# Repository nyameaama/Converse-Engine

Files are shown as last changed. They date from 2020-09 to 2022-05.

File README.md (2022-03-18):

# Converse-Engine

Pressure-Fed Cycle Based Liquid Rocket Engine integrated as a thruster.

**Propellants:**

Fuel : C3H8(L) 100%

Oxidizer: N20(L)

**Properties:**

Specific impulse (vac) : 268.45 s

Chamber Pressure : 700 psi

<p align = "center">
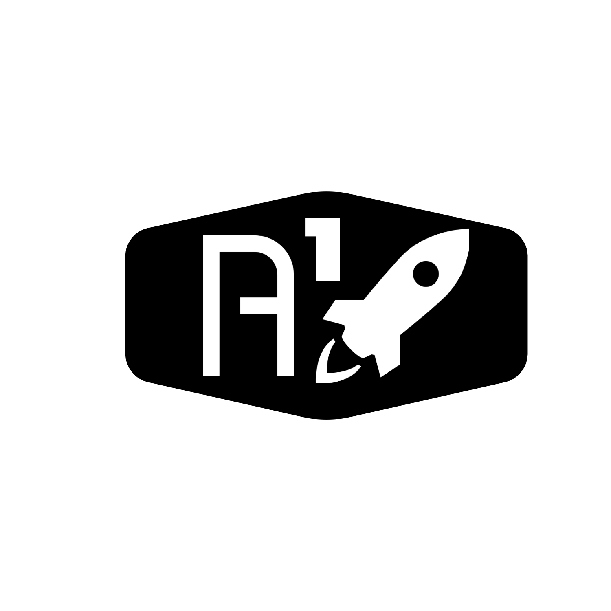
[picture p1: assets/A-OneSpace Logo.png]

</p>
<p align = "center">
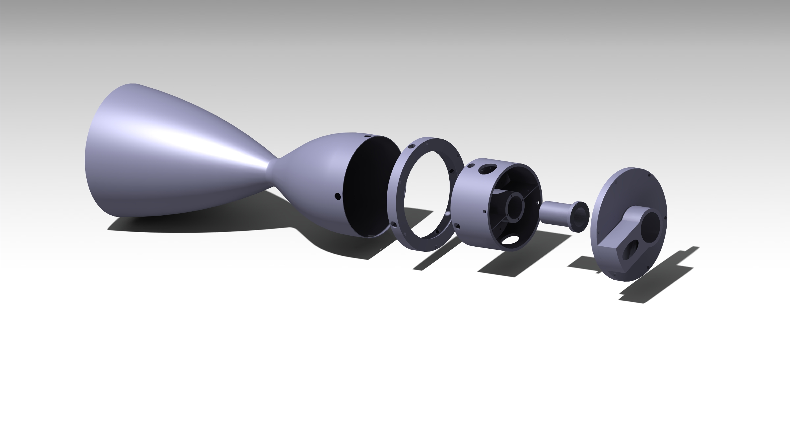
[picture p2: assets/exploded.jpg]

</p>
<p align = "center">
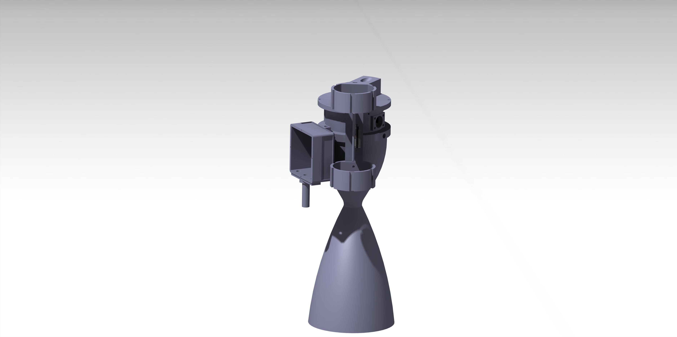
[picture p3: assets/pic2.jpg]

</p>
<p align = "center">
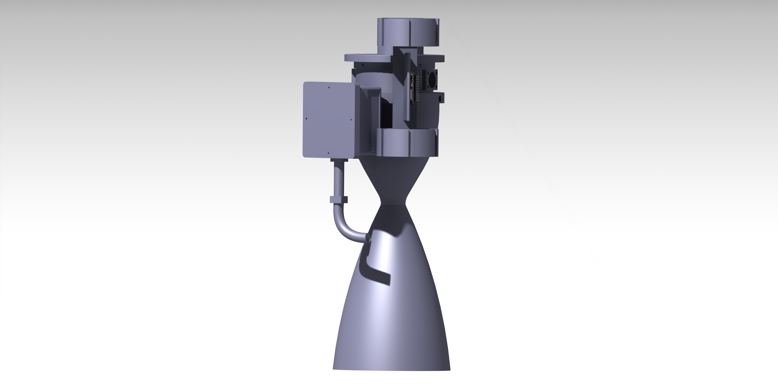
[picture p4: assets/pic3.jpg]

</p>

[A-OneSpace](https://github.com/A-OneSpace)

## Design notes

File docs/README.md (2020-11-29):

## Engine Docs

<p align = "center">
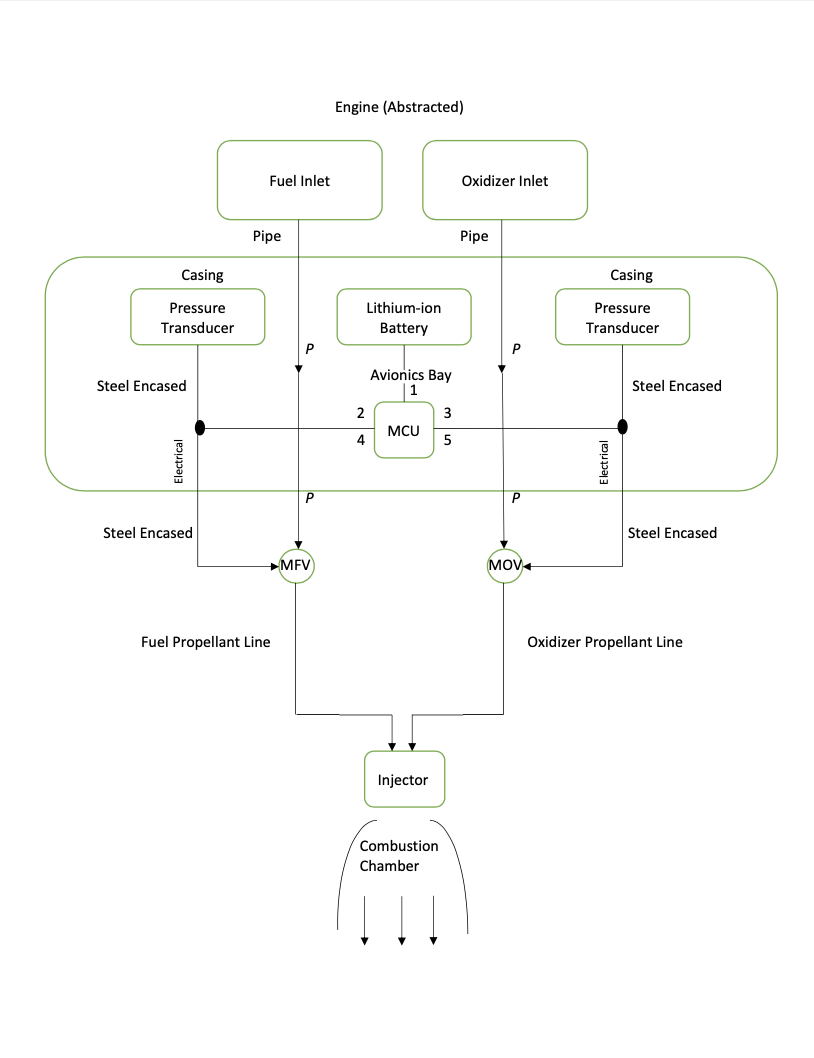
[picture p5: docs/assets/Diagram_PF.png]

</p>

See [Engine Abstracted](https://github.com/nyameaama/Converse-Engine/blob/master/docs/Engine%20Abstracted.pdf)

Pumps Battery and spark igniter documented separately. [See document]()

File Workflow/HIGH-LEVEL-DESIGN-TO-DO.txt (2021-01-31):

HIGH-LEVEL-DESIGN

Previous

- Begin detailing of purge system
- Jumper Wire detailing
- Electrical Piping analysis
- create scaled circuit
- Pipe Coupling detailing
- Begin pressure loss calculations

Current

- Updated Pressure Fed Cycle Design
- complete Engine equations
- nozzle expansion ratio lookover
- Nitrogen Gas Tank Design(Purge Sys)
- Helium Gas Tanks
- Power Assemblies

- Propellant piping analysis (Material, sizing)
- Regen cooling analysis
- injector assembly 

- pump analysis (Electric Pump Variant)
- Purge Valves (route)
- 2 way pipe (Purge Piping)

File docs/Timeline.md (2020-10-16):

# Design Stages and Timeline

Stage X - Avionics

- Sensor Component Analysis (Bill of Materials + Datasheets)
- Design Custom PCB (STM32H7 mcu)
- Avionics Unit Design
- Engine Control Unit Software
- Component Casings CAD

Stage XX - General Design 

- Requirements Analysis (Propellants)
- Nozzle Design
- Combustion Chamber Design
- Pintle injector
- Design CAD

Stage XXX - Piping and Plumbing

- Components Analysis (Pumps, Solenoid Valves)
- Pipe routing (Avionics, Propellant)

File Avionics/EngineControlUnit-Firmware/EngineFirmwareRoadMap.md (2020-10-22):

# Firmware RoadMap

STM32F7 

## Component Drivers Development

Control:
- Solenoid Valve
- Pump 

Measurement:
- Pressure Transducers
- Thermocouple

## Battery Management 

- Lithium Ion Battery Interface

## Engine Control

- Starting enigine
- Terminating engine

## AETS (Automatic Engine Termination System)

- AETS compares simulation data to actual engine performance. If operation is not in bounds engine is terminated

## Telemetry-Communication Module

-  Compile transducer and thermocouple data and send comms

## Engine Setup

- State
* ARMED -> 1 minute timer |  
* PREP -> 
* IDLE -> NO PROCESS | init terminal connection

** IF CONNECTION TO TERMINAL-CONTROLLER BREAKS, ENGINE OPERATION STOPS

Pre-conditioning Systems

- Engine Chill
* Check pipe temps
* if temps < (t(nominal)) -> Start chill
* Open LOX valves
* Pipe temp Feedback Control

- Engine Purging
* Remove residual propellant through gas flow

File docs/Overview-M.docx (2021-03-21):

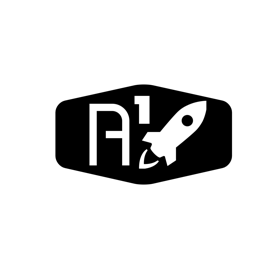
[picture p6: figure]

DESIGN DOCUMENT

Area : Converse Engine

Category: Feed (Struct)

TEAM: Propulsion

Nyameaama Gambrah

Injector Assembly

Engine Mount

Merge Plates

Merge Plates

Chamber

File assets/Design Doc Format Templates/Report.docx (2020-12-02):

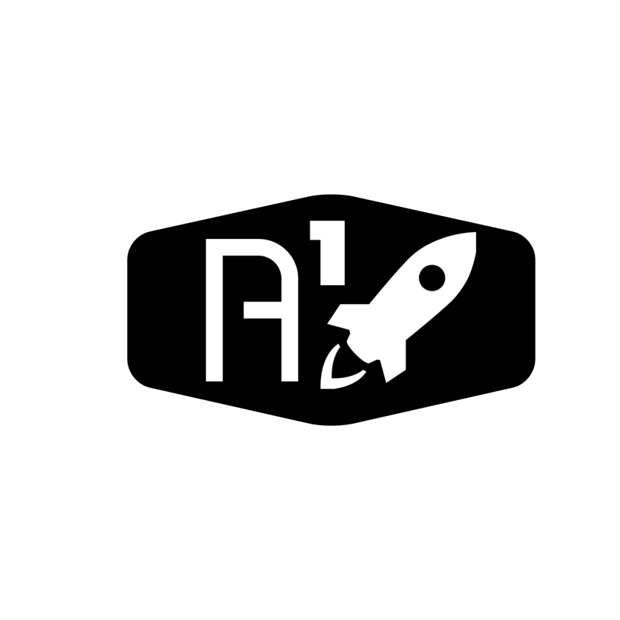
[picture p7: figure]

Lead: ……………………………

Nov 26, 2020

Nyameaama Gambrah

A-OneSpace : Converse Engine Chamber Nozzle Design

ABSTRACT

Lorem ipsum dolor sit amet, consectetur adipiscing elit, sed do eiusmod tempor incididunt ut labore et dolore magna aliqua. Tincidunt eget nullam non nisi. Amet risus nullam eget felis eget nunc lobortis mattis aliquam. Suspendisse in est ante in. Sit amet facilisis magna etiam. Nunc mattis enim ut tellus elementum sagittis vitae et. Ut porttitor leo a diam sollicitudin. Id volutpat lacus laoreet non curabitur gravida arcu. Dignissim sodales ut eu sem integer vitae justo eget. A condimentum vitae sapien pellentesque habitant. Eu lobortis elementum nibh tellus molestie nunc non. Sit amet consectetur adipiscing elit duis tristique sollicitudin nibh sit.

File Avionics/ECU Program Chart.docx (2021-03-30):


DESIGN DOCUMENT

Area : Converse Engine

Category: Feed (Avionics)

TEAM: Propulsion

Nyameaama Gambrah

CONVERSE ENGINE CONTROL UNIT PROGRAM MODULES (ABSTRACTED)

Entry

Communication Module

Utility Module

Driver Router Module

RF Comms Driver

Program Temporary Access Memory

Measurement/ Analysis Module

d

GPIO

Engine Config

Pressure-T Drivers

Valve Drivers

Parser

FLASH STORE

Telemetry Packaging

Temp Drivers

Timers

Spark Plug Drivers

SBC-Comms

Engine Properties Calculations

Control Module

Testing

Set engine config

STATE MACHINE

Abort Manager

Telemetry

Active Operation

Preconditioning

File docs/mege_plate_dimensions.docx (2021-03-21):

DESIGN DOCUMENT

Area : Converse Engine

Category: Feed (Struct)

TEAM: Propulsion

Nyameaama Gambrah

MERGE PLATE

M-Bolt

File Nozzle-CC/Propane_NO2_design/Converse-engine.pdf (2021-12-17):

## Engine name: Converse

Mon Nov 29 20:46:48 2021

Propellant Specification
Component Temperature (K) Mass fraction Mole fraction
C3H8(L) | 231.08 | 0.19 | 0.18
N2O(L),298.15K | 298.15 | 0.81 | 0.82
| Total | 1.00 | 1.00
Exploded propellant formula:N1.630 O0.815 C0.555 H1.479
| O/F = 4.400
O/F⁰ = 9.981 (stoichiometric) αox = 0.441 (oxidizer excess coefficient)

Table 1. Thermodynamic properties

Parameter | Injector | Nozzle inlet | Nozzle throat | Nozzle exit | Unit
Pressure | 3.4474 | 3.4474 | 1.8973 | 0.0117 | MPa
Temperature | 2400.6726 | 2400.6726 | 2116.4505 | 823.2841 | K
Enthalpy | 666.6951 | 666.6951 | 129.7272 | -2476.5175 | kJ/kg
Entropy | 10.9970 | 10.9970 | 10.9970 | 10.9970 | kJ/(kg·K)
Internal energy | -290.2740 | -290.2740 | -713.5100 | -2790.7130 | kJ/kg
Specific heat (p=const) | 1.9405 | 1.9405 | 1.8640 | 10.3246 | kJ/(kg·K)
Specific heat (V=const) | 1.5351 | 1.5351 | 1.4634 | 8.7935 | kJ/(kg·K)
Gamma | 1.2641 | 1.2641 | 1.2738 | 1.1741
Isentropic exponent | 1.2636 | 1.2636 | 1.2736 | 1.1169
Gas constant | 0.3986 | 0.3986 | 0.3984 | 0.3816 | kJ/(kg·K)
Molecular weight (M) | 20.8579 | 20.8579 | 20.8686 | 21.7864
Molecular weight (MW) | 0.02086 | 0.02086 | 0.02087 | 0.02124
Density | 3.6024 | 3.6024 | 2.2500 | 0.0372 | kg/m³
Sonic velocity | 1099.6349 | 1099.6349 | 1036.3089 | 592.3949 | m/s
Velocity | 0.0000 | 0.0000 | 1036.3089 | 2507.2745 | m/s
Mach number | 0.0000 | 0.0000 | 1.0000 | 4.2324
Area ratio | infinity | infinity | 1.0000 | 25.0000
Mass flux | 0.0000 | 0.0000 | 2331.7360 | 93.2322 | kg/(m²·s)
Mass flux (relative) | 0.000e-04 | 0.000e-04 | | | kg/(N·s)
Viscosity | 7.56e-05 | 7.56e-05 | 6.929e-05 | 3.673e-05 | kg/(m·s)
Conductivity, frozen | 0.2451 | 0.2451 | 0.2198 | 0.1049 | W/(m·K)
Specific heat (p=const), frozen | 1.852 | 1.852 | 1.822 | 1.581 | kJ/(kg·K)
Prandtl number, frozen | 0.5711 | 0.5711 | 0.5744 | 0.5533
Conductivity, effective | 0.2826 | 0.2826 | 0.2332 | nan | W/(m·K)
Specific heat (p=const), effective | 1.941 | 1.941 | 1.864 | 1.581 | kJ/(kg·K)
Prandtl number, effective | 0.5191 | 0.5191 | 0.5539 | nan

Table 2. Fractions of the combustion products

Species | Injector Injector Nozzle inlet Nozzle inlet mass | mole
mass | mole fractions | fractions fractions
fractions

Nozzle Nozzle Nozzle exit Nozzle exit throat throat mass mole
mass | mole | fractions | fractions
| | | | | fractions | fractions
C(gr) | | | | | | | 0.0141885 0.0250908
CH4 | 0.0000002 | 0.0000002 | 0.0000002 | 0.0000002 | 0.0000002 | 0.0000003 | 0.0066388 0.0087896
CO | 0.3288592 | 0.2448866 | 0.3288592 | 0.2448866 | 0.3256783 | 0.2426427 | 0.1754557 0.1330459
CO2 | 0.0377299 | 0.0178817 | 0.0377299 | 0.0178817 | 0.0427448 | 0.0202689 | 0.2085925 0.1006702
1
Species | Injector mass fractions
Injector Nozzle inlet Nozzle inlet | Nozzle
| | | | | throat mass fractions | | Nozzle Nozzle exit Nozzle exit
| | mole fractions | mass fractions | mole fractions | | throat mole fractions
mass | mole
fractions | fractions
COOH | 0.0000003 | 0.0000001 | 0.0000003 | 0.0000001
H | 0.0000650 | 0.0013455 | 0.0000650 | 0.0013455 | 0.0000190 | 0.0003941
H2 | 0.0236045 | 0.2442308 | 0.0236045 | 0.2442308 | 0.0238767 | 0.2471740 | 0.0266082 0.2803491
H2O | 0.0910036 | 0.1053628 | 0.0910036 | 0.1053628 | 0.0890350 | 0.1031366 | 0.0498966 0.0588273
HCHO,formaldehy | 0.0000012 | 0.0000008 | 0.0000012 | 0.0000008 | 0.0000007 | 0.0000005
HCN | 0.0000148 | 0.0000114 | 0.0000148 | 0.0000114 | 0.0000085 | 0.0000066
HCO | 0.0000026 | 0.0000019 | 0.0000026 | 0.0000019 | 0.0000007 | 0.0000005
HCOOH | 0.0000007 | 0.0000003 | 0.0000007 | 0.0000003 | 0.0000004 | 0.0000002
HNC | 0.0000014 | 0.0000011 | 0.0000014 | 0.0000011 | 0.0000005 | 0.0000004
HNCO | 0.0000029 | 0.0000014 | 0.0000029 | 0.0000014 | 0.0000016 | 0.0000008
N2 | 0.5185805 | 0.3861180 | 0.5185805 | 0.3861180 | 0.5185934 | 0.3863262 | 0.5185982 0.3932003
NH2 | 0.0000005 | 0.0000007 | 0.0000005 | 0.0000007 | 0.0000001 | 0.0000001
NH3 | 0.0000246 | 0.0000302 | 0.0000246 | 0.0000302 | 0.0000199 | 0.0000244 | 0.0000213 0.0000266
NO | 0.0000111 | 0.0000077 | 0.0000111 | 0.0000077 | 0.0000014 | 0.0000010
O | 0.0000003 | 0.0000004 | 0.0000003 | 0.0000004
OH | 0.0000963 | 0.0001181 | 0.0000963 | 0.0001181 | 0.0000184 | 0.0000226

Table 3. Theoretical (ideal) performance
Parameter | Sea level | Sea level (flow sep.) | Optimum expansion | Vacuum | Unit
Characteristic velocity | | | 1478.46 | | m/s
Effective exhaust velocity | 1545.78 | 1768.87 | 2507.27 | 2632.59 | m/s
Specific impulse (by mass) | 1545.78 | 1768.87 | 2507.27 | 2632.59 | N·s/kg
Specific impulse (by weight) | 157.63 | 180.37 | 255.67 | 268.45 | s
Thrust coefficient | 1.0455

Table 4. Estimated delivered performance

1.1964 | 1.6959 | 1.7806
Parameter | Sea level | Sea level (flow sep.) | Optimum expansion | Vacuum | Unit
Characteristic velocity | | | 1438.85 | | m/s
Effective exhaust velocity | 1417.46 | 1643.14 | 2378.95 | 2504.26 | m/s
Specific impulse (by mass) | 1417.46 | 1643.14 | 2378.95 | 2504.26 | N·s/kg

Specific impulse (by weight) | 144.54 | 167.55 | 242.59 | 255.36

s
Thrust coefficient | 0.9851 | 1.1420 | 1.6534 | 1.7405
Ambient condition for optimum expansion: H=15.23 km, p=0.115 atm
2

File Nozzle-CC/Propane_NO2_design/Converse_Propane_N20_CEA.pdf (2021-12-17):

NASA-GLENN CHEMICAL EQUILIBRIUM PROGRAM CEA2, FEBRUARY 5, 2004 BY BONNIE MCBRIDE AND SANFORD GORDON REFS: NASA RP-1311, PART I, 1994 AND NASA RP-1311, PART II, 1996

*******************************************************************************

### CEA analysis performed on Tue 14-Dec-2021 15:02:54

# Problem Type: "Rocket" (Infinite Area Combustor)

prob case=Converse_______2705 ro equilibrium

# Pressure (1 value):

p,psia= 750
# Chamber/Exit Pressure Ratio (1 value): pi/p= 51.02

# Oxidizer/Fuel Wt. ratio (1 value):

o/f= 4.4

# You selected the following fuels and oxidizers: reac

fuel C3H8(L) | wt%=100.0000
oxid N2O | wt%=100.0000

# You selected these options for output:

# short version of output

output short
# Proportions of any products will be expressed as Mass Fractions. output massf

# Heat will be expressed as siunits

output siunits

# Input prepared by this script:/var/www/sites/cearun.grc.nasa.gov/cgi-bin/CEARU N/prepareInputFile.cgi

### IMPORTANT: The following line is the end of your CEA input file!

end

THEORETICAL ROCKET PERFORMANCE ASSUMING EQUILIBRIUM

COMPOSITION DURING EXPANSION FROM INFINITE AREA COMBUSTOR

Pin = 750.0 PSIA
CASE = Converse_______
REACTANT | WT FRACTION | ENERGY | TEMP
(SEE NOTE) | KJ/KG-MOL | K
FUEL | C3H8(L) | 1.0000000 | -128228.000 | 231.076
OXIDANT | N2O | 1.0000000 | 0.000 | 0.000
O/F= | 4.40000 | %FUEL= 18.518519 | R,EQ.RATIO= 2.268459 | PHI,EQ.RATIO= 2.268459
CHAMBER | THROAT | EXIT
Pinf/P | 1.0000 | 1.8248 | 51.020
P, BAR | 51.710 | 28.338 | 1.0135
T, K | 1751.69 | 1532.82 | 906.28
RHO, KG/CU M | 7.4122 0 4.6426 0 2.9816-1
H, KJ/KG | -538.51 | -931.32 -2414.33
U, KJ/KG | -1236.15 -1541.71 -2754.26
G, KJ/KG | -18495.7 -16644.7 -11704.9
S, KJ/(KG)(K) | 10.2513 | 10.2513 | 10.2513
M, (1/n) | 20.877 | 20.880 | 22.167
MW, MOL WT | 20.877 | 20.880 | 21.655
(dLV/dLP)t | -1.00030 -1.00056 -1.05903
(dLV/dLT)p | 1.0018 | 1.0045 | 2.0623
Cp, KJ/(KG)(K) | 1.8066 | 1.7967 | 9.2320
GAMMAs | 1.2836 | 1.2871 | 1.1284
SON VEL,M/SEC | 946.3 | 886.4 | 619.3
MACH NUMBER | 0.000 | 1.000 | 3.127

PERFORMANCE PARAMETERS

Ae/At | 1.0000 | 7.1255
CSTAR, M/SEC | 1256.6 | 1256.6
CF | 0.7054 | 1.5414
Ivac, M/SEC | 1575.0 | 2112.4
Isp, M/SEC | 886.4 | 1936.9

MASS FRACTIONS

CH4 | 0.00003 | 0.00008 | 0.01386
*CO | 0.31866 | 0.31151 | 0.17791
*CO2 | 0.05367 | 0.06478 | 0.18999
HCN | 0.00003 | 0.00002 | 0.00000
*H2 | 0.02437 | 0.02486 | 0.02326
H2O | 0.08463 | 0.08013 | 0.06355
NH3 | 0.00011 | 0.00011 | 0.00007
*N2 | 0.51851 | 0.51852 | 0.51855
C(gr) | 0.00000 | 0.00000 | 0.01280

* THERMODYNAMIC PROPERTIES FITTED TO 20000.K

NOTE. WEIGHT FRACTION OF FUEL IN TOTAL FUELS AND OF OXIDANT IN TOTAL OXIDANTS

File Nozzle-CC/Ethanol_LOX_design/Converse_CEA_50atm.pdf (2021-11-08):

NASA-GLENN CHEMICAL EQUILIBRIUM PROGRAM CEA2, FEBRUARY 5, 2004 BY BONNIE MCBRIDE AND SANFORD GORDON REFS: NASA RP-1311, PART I, 1994 AND NASA RP-1311, PART II, 1996

*******************************************************************************

### CEA analysis performed on Sat 06-Nov-2021 15:56:00

# Problem Type: "Rocket" (Infinite Area Combustor)

prob case=_______________1041 ro equilibrium

# Pressure (1 value):

p,atm= 50
# Chamber/Exit Pressure Ratio (1 value): pi/p= 50

# Oxidizer/Fuel Wt. ratio (1 value):

o/f= 1.3

# You selected the following fuels and oxidizers: reac

fuel C2H5OH | wt%=100.0000
oxid O2 | wt%=100.0000

# You selected these options for output:

# short version of output

output short
# Proportions of any products will be expressed as Mass Fractions. output massf

# Heat will be expressed as siunits

output siunits

# Input prepared by this script:/var/www/sites/cearun.grc.nasa.gov/cgi-bin/CEARU N/prepareInputFile.cgi

### IMPORTANT: The following line is the end of your CEA input file!

end

THEORETICAL ROCKET PERFORMANCE ASSUMING EQUILIBRIUM

COMPOSITION DURING EXPANSION FROM INFINITE AREA COMBUSTOR

Pin = 734.8 PSIA
CASE = _______________
REACTANT | WT FRACTION | ENERGY | TEMP
(SEE NOTE) | KJ/KG-MOL | K
FUEL | C2H5OH | 1.0000000 | 0.000 | 0.000
OXIDANT | O2 | 1.0000000 | 0.000 | 0.000
O/F= | 1.30000 | %FUEL= 43.478261 | R,EQ.RATIO= 1.475797 | PHI,EQ.RATIO= 1.602906
CHAMBER | THROAT | EXIT
Pinf/P | 1.0000 | 1.7358 | 50.000
P, BAR | 50.663 | 29.188 | 1.0132
T, K | 3635.79 | 3440.20 | 2297.51
RHO, KG/CU M | 3.3238 0 2.0512 0 1.1208-1
H, KJ/KG | 0.00000 | -812.23 -4695.86
U, KJ/KG | -1524.22 -2235.20 -5599.90
G, KJ/KG | -46826.0 -45119.2 -34286.0
S, KJ/(KG)(K) | 12.8792 | 12.8792 | 12.8792
M, (1/n) | 19.833 | 20.101 | 21.130
(dLV/dLP)t | -1.03555 -1.02889 -1.00147
(dLV/dLT)p | 1.6057 | 1.5209 | 1.0377
Cp, KJ/(KG)(K) | 6.7134 | 6.2566 | 2.6229
GAMMAs | 1.1435 | 1.1416 | 1.1906
SON VEL,M/SEC | 1320.2 | 1274.5 | 1037.5
MACH NUMBER | 0.000 | 1.000 | 2.954

PERFORMANCE PARAMETERS

Ae/At | 1.0000 | 7.6112
CSTAR, M/SEC | 1937.9 | 1937.9
CF | 0.6577 | 1.5814
Ivac, M/SEC | 2391.0 | 3359.6
Isp, M/SEC | 1274.5 | 3064.6

MASS FRACTIONS

*CO | 0.41573 | 0.40807 | 0.36716
*CO2 | 0.17741 | 0.18949 | 0.25382
COOH | 0.00003 | 0.00002 | 0.00000
*H | 0.00224 | 0.00188 | 0.00019
HCO | 0.00004 | 0.00002 | 0.00000
HO2 | 0.00008 | 0.00004 | 0.00000
*H2 | 0.01579 | 0.01550 | 0.01641
H2O | 0.32462 | 0.33529 | 0.36097
H2O2 | 0.00001 | 0.00001 | 0.00000
*O | 0.00658 | 0.00455 | 0.00002
*OH | 0.04591 | 0.03665 | 0.00139
*O2 | 0.01156 | 0.00849 | 0.00004

* THERMODYNAMIC PROPERTIES FITTED TO 20000.K

NOTE. WEIGHT FRACTION OF FUEL IN TOTAL FUELS AND OF OXIDANT IN TOTAL OXIDANTS

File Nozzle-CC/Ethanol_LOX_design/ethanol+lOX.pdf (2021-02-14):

## Liquid Oxygen & Ethyl Alcohol*

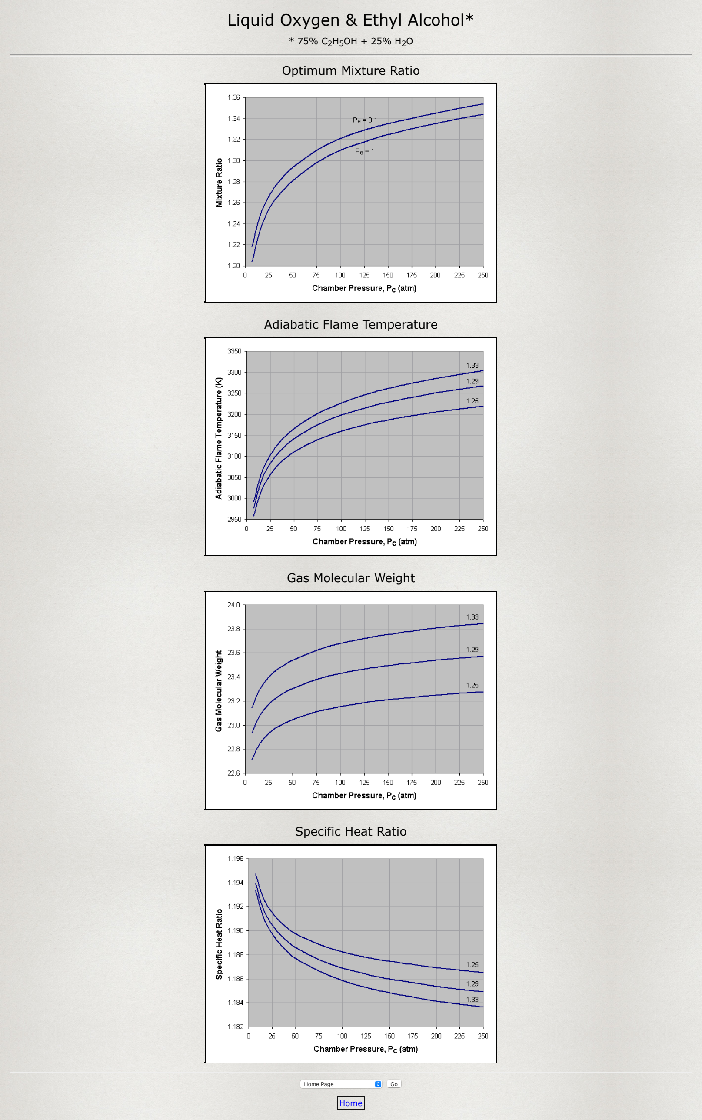
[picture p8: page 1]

* 75% C2H5OH + 25% H2O

Optimum Mixture Ratio

Adiabatic Flame Temperature

Gas Molecular Weight

Specific Heat Ratio

Home Page | Go

Home

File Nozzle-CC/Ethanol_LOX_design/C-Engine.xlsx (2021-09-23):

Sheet: VesselCharacteristics
 | Characteristics of a Vehicle in Motion |  |  |  |  |  |  |  |  |  |  |  |  |  |  |  |  |  |  |  |  |  | Chamber & Nozzle Measurements For Graph
 |  |  |  |  |  |  |  | 7.911e-05 | 5 | 0.005 |  |  |  |  |  |  |  |  |  | Propellent Mass Budget Analysis for Change in Velocity Increment |  |  | x | y-top | y-bottom | y-top-outer | y-bottom-outer | y-tube-top-upper | y-tube-top-lower | y-tube-bottom-upper | y-tube-bottom-lower
Instructions: This advanced equation takes a number of bipropellant liquid engine inputs and models a variety of outputs including: velocity, altitude, acceleration, nozzle dimensions, and heat-transfer. All input data should be filled in the yellow boxes. Anything in grey will be calculated automatically and green values are key outputs also calculated automatically. The charts will also update automatically. Note that thermal conductivity calculations do not consider carbon deposits or nucleate boiling |  |  |  |  |  |  |  |  |  |  |  |  |  |  |  |  |  |  |  | Velocity Increase (m/sec) | Propellent Mass (kg) | Change in Propellent Mass (kg) | 0 | 4.17130 | 0.303 | 4.47432 | 0.205 | 4.22051 | 4.37590 | 0.25381 | 0.0984251967
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

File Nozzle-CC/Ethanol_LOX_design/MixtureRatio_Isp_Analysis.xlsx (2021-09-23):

Mixture Ratio Analysis
Fuel-Rich | 100% Ethanol |  |  | Oxidizer-Rich | 100% Ethanol
Ratio (O/F) | Calculated Isp |  | Chamber Temp | Ratio (O/F) | Calculated Isp |  | Chamber Temp
 | (sec) | (m/sec) |  |  | (sec) | (m/sec) | (K)
1.1 | 264.8877551 | 2595.9 | 2780.28 | 1.1 | 264.8877551 | 2595.9 | 2780.28
1.2 | 271.3469388 | 2659.2 | 2983.22 | 2.1 | 278.7755102 | 2732 | 3453.72
1.3 | 276.4489796 | 2709.2 | 3145.17 | 3.1 | 258.7959184 | 2536.2 | 3311.35
1.4 | 280.2857143 | 2746.8 | 3265.37 | 4.1 | 241.2244898 | 2364 | 3117.26
1.5 | 282.9285714 | 2772.7 | 3347.88 | 5.1 | 225.8061224 | 2212.9 | 2911.2

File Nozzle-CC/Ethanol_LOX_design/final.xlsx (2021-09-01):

Final
Force Max (Fmax) = | 10000.00
Fuel/Oxidizer Specific Heat Ratio (k) | 1.185 | (Dimensionless)
Molecular Mass of Propellant Mixture (M) = | 24 | (Dimensionless)
Gas Constant (R) = | 8314 | j/Kg-K
Chamber Temperature (T1) = | 3030 | kelvin
Nozzle Inlet/Chamber Pressure (p1) = | 5.065578181 | pascal
Nozzle Exit Pressure (p2) = | 0.101325353 | pascal
Atomospheric Pressure (p3) = | 0.101325353 | pascal
Pressure Ratio (p2/p1) = | 0.02000272
Nozzle Throat Pressure (pt)= | 2.874247
Exhaust Velocity (v2) = | 12144.82 | m/sec
*Actual* Characteristic Velocity (c*) = | 7774.177582 | m/sec
Nozzle Area Ratio (At/A2) = | 0.1381
Thrust Coefficient (CF) = | 1.5622
Chamber Contraction Ratio (A1/At) = | 6.00
Chamber Cross Sectional Area = | 0.00758 | meters2
Chamber Diameter = | 0.09825 | meters
Chamber Length (L1)= | 0.1016 | meters
Nozzle Cone Convergence Half Angle (α) = | 60 | degrees
Convergence Length = | 0.01678419 | meters
Conical Frustum Length (Lc) = | 0.03356837 | meters
Chamber Volume (Vc)= | 0.001171195 | meters3
Chamber Characteristic Length (L*) = | 0.9268 | meters
Nozzle Throat Area = | 0.00126369 | meters2
Nozzle Throat Diameter = | 0.04011 | meters
Nozzle Throat Length = | 0.00079 | meters
Nozzle Exit Area = | 0.00915 | meters2
Nozzle Exit Diameter = | 0.10795 | meters
Nozzle Cone Diverence Half Angle (α) = | 15 | degrees
Nozzle Length = | 0.126584088 | meters
Nozzle Frustm Length (Nc) = | 0.131049491 | meters
Chamber Wall Thickness = | 0.0025 | meters

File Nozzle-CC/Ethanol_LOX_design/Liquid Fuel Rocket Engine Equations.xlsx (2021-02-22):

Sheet: Design
F | 23000 |  |  |  | Thrust, lbf
ωt | 63.55346781 |  |  |  | Propellant flow rate, lbs/s
Isp | 361.9 |  |  |  | Found in Flame Temps and Isp's
ωo | 45.39533415 |  |  |  | Oxidizer flow rate, lbs/s
ωf | 18.15813366 |  |  |  | Fuel flow rate, lbs/s
r | 2.5 |  |  |  | Mixture Ratio, found in tables
Tt | 5547.01797 |  |  |  | Throat Temperature
Tc | 6102.33 |  |  |  | Chamber Temperature
ºF | 5642.33 |  |  |  | Combustion Temperature, tables
Pt | 169.2 |  |  |  | Throat Pressure
Pc | 300 |  |  |  | Chamber Pressure, Tables
At | 36.2833017 |  | At01 | 0.3756115119 | Throat Area | At02 | 360556.168 | At03 | 38.64 | At04 | 9331.163769 | At05 | 96.5979491 | At06 | 36.2833017
R | 65 |  |  |  | Gas Constant
γ | 1.2 |  |  |  | Gamma
g | 32.2 |  |  |  | gravity
Dt | 6.79686211 | 3.398431055 |  |  | Throat Diameter, inches
π | 3.141592654 |  |  |  | pi
Ae | 132.4340512 |  |  |  | Exit area
De | 12.98538683 | 6.492693414 |  |  | Exit Diameter, inches
β | 60 | 30 | 0.5235987756 |  | Nozzle Angles
α | 15 | 75 | 1.308996939 | 0.2617993878
Lnozzle | 33.72892737 |  |  |  | Nozzle Length, in
Lconvergent | 12.68311736 |  |  |  | Convergent length, in
Ldivergent | 21.04581 |  |  |  | Divergent Length, in
L* | 60 |  |  |  | Don’t change
Vc | 2176.998102 |  |  |  | Chamber Volume, in^3
Dc | 33.98431055 |  |  |  | Chamber Diameter, in
Ac | 145.1332068 |  |  |  | Chamber Area, in
Lc | 287231.5598 |  |  |  | Chamber Length, in
Dtmm | 172.6402976 |  |  |  | Metric conversions
Lcmm | 7295681.619 |  |  |  | -
Dcmm | 863.201488 |  |  |  | -

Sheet: Printable Results
Throat Diameter | 172.6402976 | mm
Exit Diameter | 329.8288254 | mm
Chamber Diamter | 863.201488 | mm
Chamber Length | 7295681.619 | mm
Length Divergent | 534.5635741 | mm
Length Convergent | 322.151181 | mm
Nozzle Length | 856.7147551 | mm

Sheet: Fabrication Stuff
V_initial | 260542733.6 | in^3
r | 16.99215528 | in
h | 287231.5598 | in
pi | 3.141592654
V_new | 260542733.6 | in^3
r | 1.5 | in
h | 36859256.83 | in

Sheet: Enthalpy Stuff
Q | 195.933 |  | Q
m | 0.723 |  | 460.272645
c | 0.47 |  | Max Burn time chamber
∆t | 1354.5 |  | 0.01212839644 | seconds
Max Burn Time both | 0.005162924901
P | 37950
 |  | BROKEN IGNORE

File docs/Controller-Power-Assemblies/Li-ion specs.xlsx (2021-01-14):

Li-ion
Dimensions |  |  | Charging/Discharging
Width | 49.2 | mm | Ref | https://learn.sparkfun.com/tutorials/battery-technologies
Length | 68.8 | mm
Depth | 5.6 | mm
Weight | 36 | g
Operating Range (Celsius)
Min | -25
Max | 60
Stock
Seller | https://www.sparkfun.com/products/13855?_ga=2.11315764.1640149509.1610657223-1662461207.1610657223

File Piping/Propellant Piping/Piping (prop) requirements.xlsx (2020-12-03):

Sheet: Docs
Propellant Piping
Mdot = Density * Flow Rate * Cross Sectional Area
Flow Rate:
Q = A * V
where A = Cross Sectional Area
V = Velocity
Pipe Diameter = sqrt(4) * Flow Rate / pi * velocity
Pi | 3.114159265

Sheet: Design
Cals
LOX Density | 1141 | kgm^3
Ethanol Density | 789 | kgm^3
Flow Rate
Velocity

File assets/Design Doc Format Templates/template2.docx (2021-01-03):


DESIGN DOCUMENT

Area : Converse Engine

Category: Feed (Piping)

TEAM: Propulsion

Nyameaama Gambrah

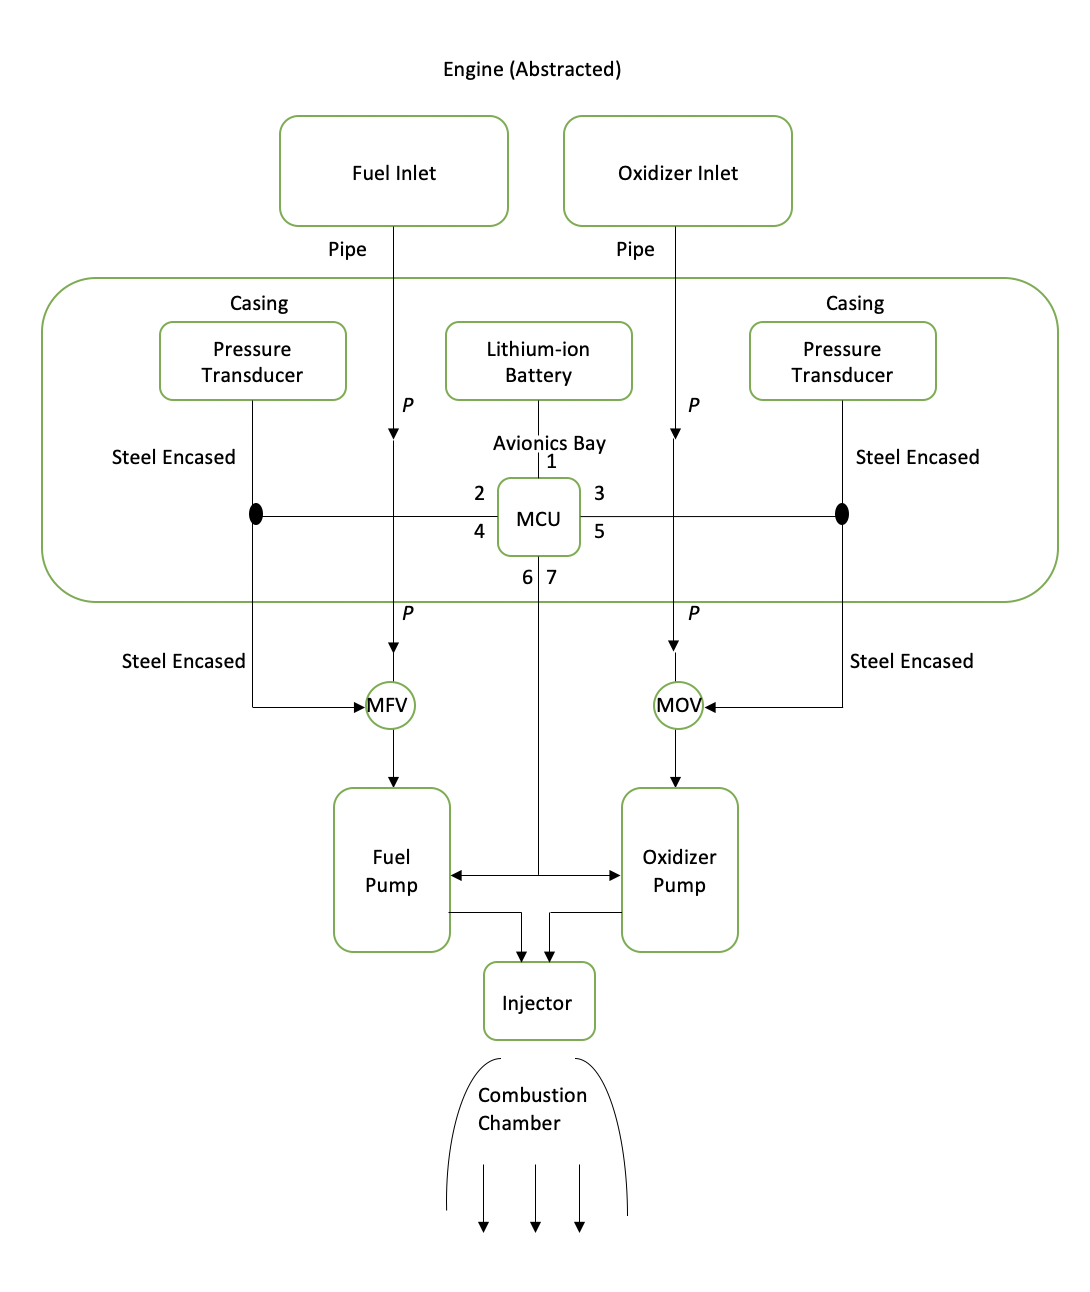
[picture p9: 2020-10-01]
docs/assets/Diagram_EF.png

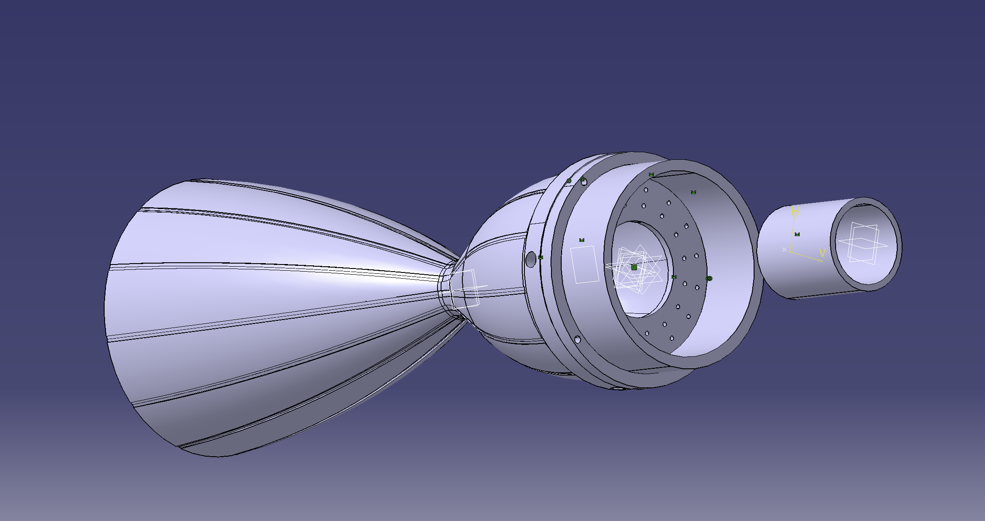
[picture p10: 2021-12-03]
assets/Screen Shot 2021-12-03 at 12.04.24 PM.png

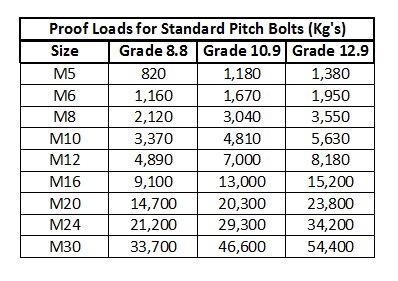
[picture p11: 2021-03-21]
Piping/proof loads of bolts.jpg

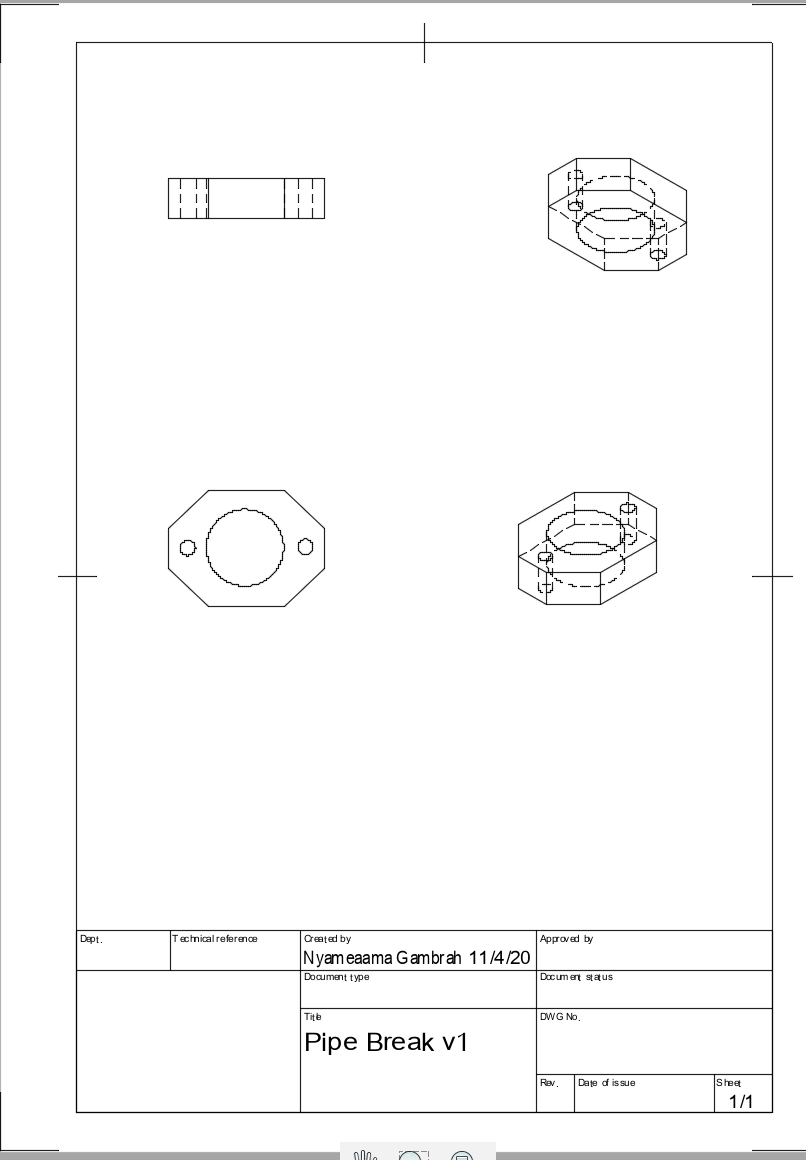
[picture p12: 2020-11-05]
Piping/Nuts-Bolts CAD/Pipe Couplings_Fitting/Pipe Break Drawing V1.png

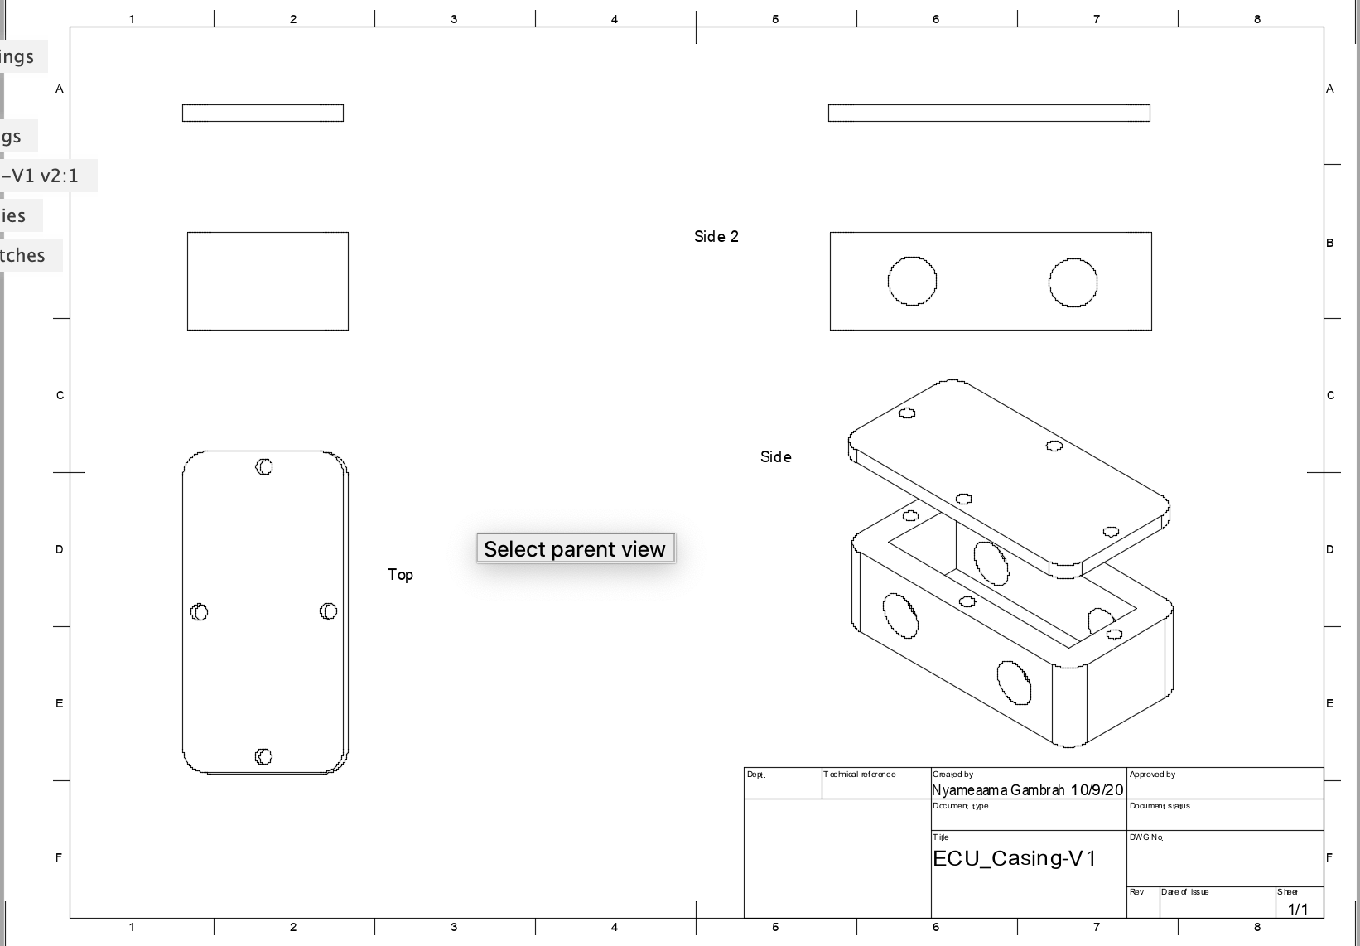
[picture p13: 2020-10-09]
Avionics/Casings/EngineControlUnit/ECU/Drawings.png

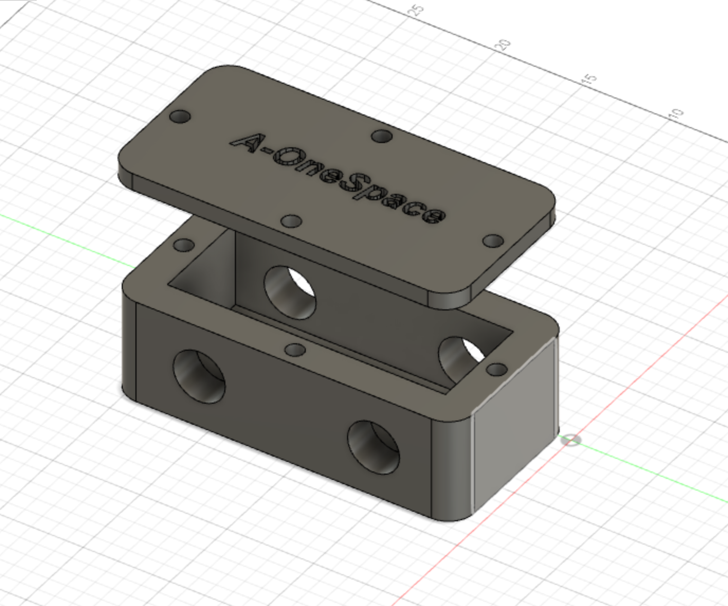
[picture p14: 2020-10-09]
Avionics/Casings/EngineControlUnit/ECU/ECU-Casing-2.png

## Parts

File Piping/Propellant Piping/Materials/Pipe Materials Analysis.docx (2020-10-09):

Pipe Materials Analysis

## Austenitic

The most common types of stainless steels are austenitic stainless steels. Compared to other types of stainless steels, austenitic stainless steels are extremely high in nickel content. Generally, they will also contain high amounts of chromium, nitrogen, and molybdenum.

Austenitic steels are renowned for their extreme weld-ability and malleability. Commonly used for kitchen cutlery and storage components, they also receive a lot of credit for their strength capabilities.

They typically have very high corrosion resistance. This suits them for a variety of uses where a corrosive environment is present. Common austenitic stainless steels include alloys 304 and 904L (N08904).

The only potential problem with austenitic stainless steel is that it’s expensive.

## Ferritic

Ferritic stainless steels (https://www.thebalance.com/metal-profile-ferritic-stainless-steel-2340133) are stainless steels with low, but existing amounts of carbon. Generally, carbon consistencies in ferritic stainless steels don’t exceed 0.10%. While other minerals can be added to these steels (molybdenum is a common additive), they primarily consist of chromium.

Ferritic stainless steels are magnetic, and are used commonly for their resistance to stress corrosion cracking. Because of this, they’re often utilized for products that will come into contact with potentially corrosive materials. These products include car components, kitchen cookware, and industrial entities.

Two of the more common types of ferritic steel are alloys 430 and 434.

## Duplex

Duplex stainless steels are essentially combinations of ferritic and austenitic stainless steels. Stronger than both ferritic and austenitic stainless steels, they possess less nickel than austenitic steels. Because of this, they are also less expensive than austenitic steels.

Duplex stainless steel is used heavily in the underwater oil industry. This is due mainly to its corrosion resistance capabilities, which allow it to withstand the corrosive nature of salt water over long periods of time.

Fairly malleable, and fairly weldable, duplex stainless steels can be shaped to create a number of different components. Two of the more common types (https://www.gpss.com/alloy-s31803-alloy-s32205-duplex-stainless-steel/) of duplex stainless steel include S31803 stainless steel and S32205 stainless steel.

## Martensitic

Martensitic stainless (https://www.bssa.org.uk/topics.php?article=253) steels are structurally similar to ferritic stainless steels, with the only real differences being their percentages of carbon. While carbon percentages in ferritic stainless steel remain below 0.10%, carbon percentages in martensitic stainless steel hover around 1%.

This difference in carbon percentages is important because it allows for martensitic stainless steels to be hardened to great extents. This type of steel is typically used in situations that call for high strength, but average resistance to corrosion. You’ll often see it used in valves or pumps, though it has many more applications aside from these.

Some martensitic stainless steels include alloy 431 and 420S45.

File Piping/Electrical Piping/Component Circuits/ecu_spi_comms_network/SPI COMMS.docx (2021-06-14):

SPI COMMS

Node MCU schematic

NodeMCU ESP8266 Pinout
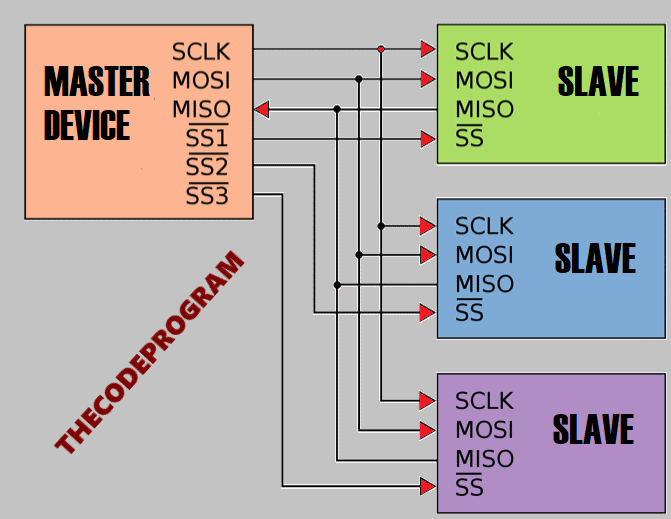
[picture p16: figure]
SPI Communication Schematic

Controller to controller connection schematic

* Each subcontroller has 2 neighbourly routes to complete the circular network topology

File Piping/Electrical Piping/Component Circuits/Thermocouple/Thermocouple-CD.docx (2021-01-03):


DESIGN DOCUMENT

Area : Converse Engine

Category: Feed (Piping)

TEAM: Propulsion

Nyameaama Gambrah

THERMOCOUPLE

CLK

CS

DO

GND

VCC

D-Pin

D-Pin

D-Pin

5V

GND

ECU

AD595 Thermocouple Amplifier

T-C

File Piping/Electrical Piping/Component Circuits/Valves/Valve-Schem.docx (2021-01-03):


DESIGN DOCUMENT

Area : Converse Engine

Category: Feed (Piping)

TEAM: Propulsion

Nyameaama Gambrah

SOLENOID VALVE

Power -Li-ion

Signal-IN

GND

VCC

GND

+5V

D-Pin

GND

DIGITAL PIN-OUT

5V

Relay Module

ECU

Valve

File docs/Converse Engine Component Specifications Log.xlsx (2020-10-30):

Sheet: Main
Converse Engine Component Specifications Log
Part Number | Part Description | Development Branch | Redirectory
CE001 | ECU Component Casing | Avionics | 0
CE002 | External Storage | Avionics
CE003 | Solenoid Valve | Avionics
CE004 | Lithium ion Battery | Avionics
CE005 | Pump | Avionics
CE006 | Spark igniter | Avionics
CE007 | Thermocouple | Avionics
CE008 | Pressure Transducer | Avionics

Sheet: CE001
Part | CE001
Width | 20 cm
Height | 10 cm
Depth | 7 cm
Inner Area | 96 cm^2
Wiring Open Area | 7.065 cm^2
Dependency
Description
Component Casing to hold the Engine Control Unit

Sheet: CE002
Part | CE002

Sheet: CE003
Part | CE003

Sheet: CE004
Part | CE004

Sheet: CE005
Part | CE005

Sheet: CE006
Part | CE006

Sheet: CE007
Part | CE007

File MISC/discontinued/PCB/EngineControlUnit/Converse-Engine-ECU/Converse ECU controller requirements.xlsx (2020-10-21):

ECU CONTROLLER REQUIREMENTS
Component | Description | Type/Purpose | Quantity | Channel Requirement | D-Pins | A-Pins | GND | VCC | Total Component Pins
External Storage |  | Measurement | 1 |  |  |  |  |  | 0
Solenoid Valve |  | Control | 2 | GPIO | 1 | 0 | 1 | 1 | 6
Lithium ion Battery |  | Utility | 1 |  |  |  |  |  | 0
Pump |  | Control | 2 |  |  |  |  |  | 0
Spark igniter |  | Control | 1 | GPIO |  |  |  |  | 0
Thermocouple |  | Measurement | 3 | GPIO | 3 | 0 | 1 | 1 | 15
Pressure Transducer |  | Measurement | 2 | GPIO |  |  |  |  | 0
 |  |  |  |  |  |  |  |  | 0
 |  |  |  |  |  |  |  |  | 0
 |  |  |  |  |  |  |  |  | 0
 |  |  |  |  |  |  |  |  | 0

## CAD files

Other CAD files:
Assemblies-CAD/ElectronicsBay_SubAssembly/BayHolder.CATPart
Assemblies-CAD/ElectronicsBay_SubAssembly/Bay_beams.CATPart
Assemblies-CAD/ElectronicsBay_SubAssembly/EBayMount.CATPart
Assemblies-CAD/ElectronicsBay_SubAssembly/E_sheetMetal.CATPart
Assemblies-CAD/ElectronicsBay_SubAssembly/Ebay2.CATProduct
Assemblies-CAD/ElectronicsBay_SubAssembly/ElectronicsA.CATPart
Assemblies-CAD/ElectronicsBay_SubAssembly/ElectronicsBay_SubAssembly.CATProduct
Assemblies-CAD/ElectronicsBay_SubAssembly/ExtendedE_TopCase.CATPart
Assemblies-CAD/ElectronicsBay_SubAssembly/ExtendedElectrical.CATPart
Assemblies-CAD/ElectronicsBay_SubAssembly/ExtendedElectricalCaseAssembly.CATProduct
Assemblies-CAD/Full_Assembly/Full_Assembly.CATProduct
Assemblies-CAD/Pipe_Electrical/E-Pipe_50_mm.CATPart
Assemblies-CAD/Pipe_Electrical/EPipe_50mm_RightAngled.CATPart
Assemblies-CAD/Pipe_Electrical/PropPipe_RightAngled.CATPart
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

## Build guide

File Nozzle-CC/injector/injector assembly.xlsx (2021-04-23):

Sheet: Sheet1
Injector Assembly
Screw Type | M10

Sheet: Calcs
Injector
Discharge Coefficient (Cd)
Oxidizer Density (Do)
Fuel Density (Df)
Oxidizer cross sectional area (Ao)
Fuel cross sectional area (Af)

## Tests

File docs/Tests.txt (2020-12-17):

Testing

PROTOCOL

Test Suite:

- Custom Spark Igniter
- Pressure Transducers
- 

HARDWARE

Test Stand

RangeSafety

-  Control Terminal (Direc Link to ECU - RF )

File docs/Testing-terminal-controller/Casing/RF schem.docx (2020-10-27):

RF

Controller

Transmitter

Transmitter

VCC

Controller

5V

GND

GND

D-Pin

Data

Receiver

Data

VCC

GND

GND

D-Pin

5V

Receiver

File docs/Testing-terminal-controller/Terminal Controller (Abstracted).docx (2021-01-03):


DESIGN DOCUMENT

Area : Converse Engine

Category: Feed (Piping)

TEAM: Propulsion

Nyameaama Gambrah

Terminal Controller (Abstracted)

Storage

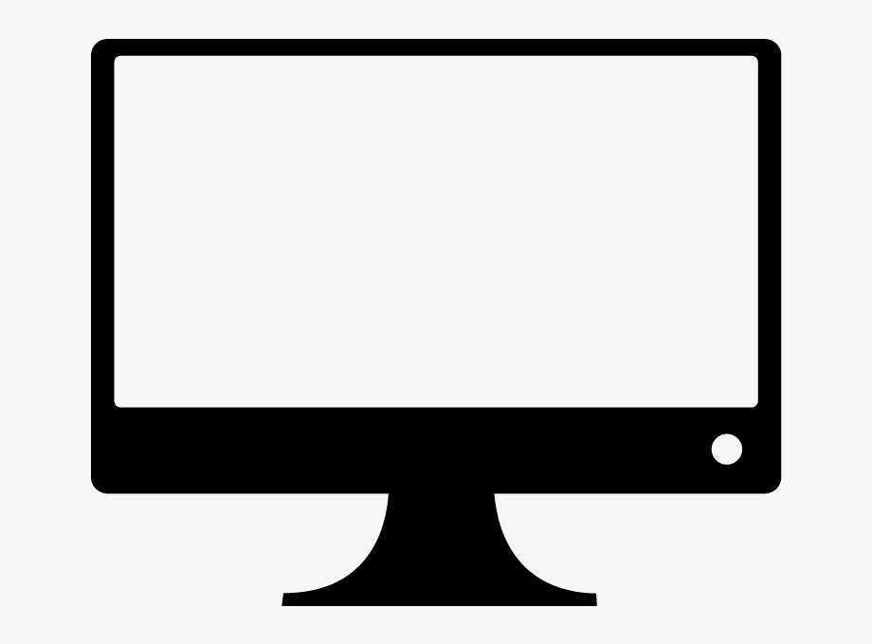
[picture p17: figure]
Computer Monitor Clipart , Png Download - Computer Monitor , Transparent Cartoon, Free Cliparts & Silhouettes - NetClipart

Commands

Commands

Serial

Telemetry

Telemetry

RF

Terminal Controller

Engine Control Unit

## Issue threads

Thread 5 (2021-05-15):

Align software to fit NASA safety critical code standards

nyameaama, 2021-05-15:
NASA’s 10 rules are:

1. Restrict all code to very simple control flow constructs—do not use goto statements, setjmp or longjmp constructs, or direct or indirect recursion.
2. Give all loops a fixed upper bound.
3. Do not use dynamic memory allocation after initialization.
4. No function should be longer than what can be printed on a single sheet of paper in a standard format with one line per statement and one line per declaration.
5. The code's assertion density should average to minimally two assertions per function.
6. Declare all data objects at the smallest possible level of scope.
7. Each calling function must check the return value of nonvoid functions, and each called function must check the validity of all parameters provided by the caller.
8. The use of the preprocessor must be limited to the inclusion of header files and simple macro definitions.
9. Limit pointer use to a single dereference, and do not use function pointers.
10. Compile with all possible warnings active; all warnings should then be addressed before release of the software.

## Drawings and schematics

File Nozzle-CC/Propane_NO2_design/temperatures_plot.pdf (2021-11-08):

## Temperature distribution at chamber throttle level R=1

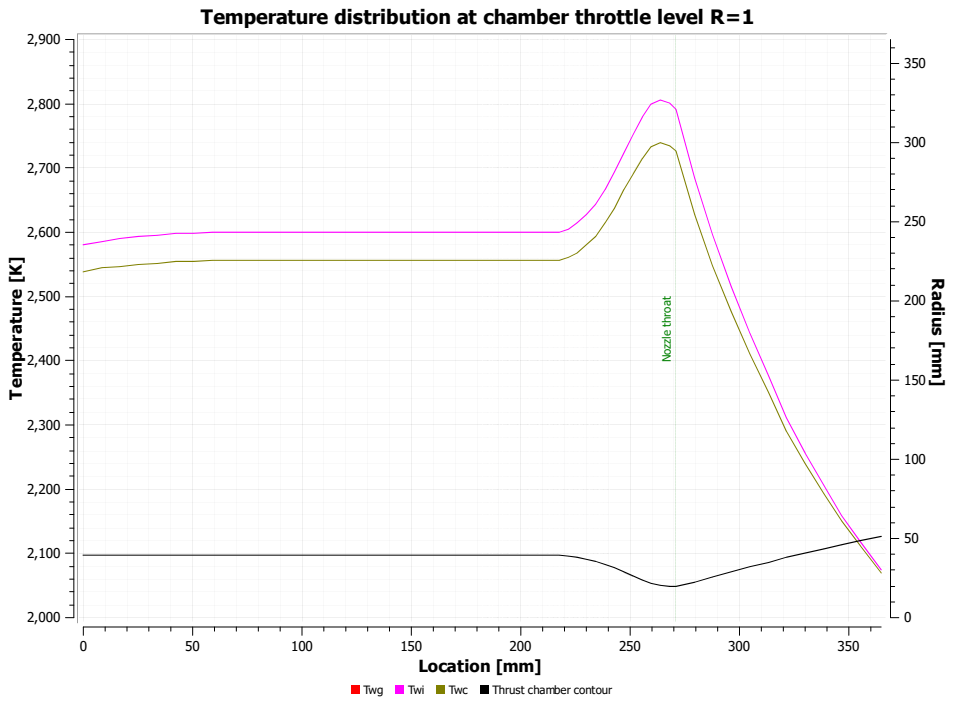
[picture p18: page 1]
Nozzle throat; Twg; Twi; Twc; Thrust chamber contour Temperature [K]; Radius [mm]; Location [mm]

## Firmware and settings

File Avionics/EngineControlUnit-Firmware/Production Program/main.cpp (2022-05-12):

/*MIT License

Copyright (c) 2020 Nyameaama Gambrah

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
THE SOFTWARE IS PROVIDED "AS IS", WITHOUT WARRANTY OF ANY KIND, EXPRESS OR
IMPLIED, INCLUDING BUT NOT LIMITED TO THE WARRANTIES OF MERCHANTABILITY,
FITNESS FOR A PARTICULAR PURPOSE AND NONINFRINGEMENT. IN NO EVENT SHALL THE
AUTHORS OR COPYRIGHT HOLDERS BE LIABLE FOR ANY CLAIM, DAMAGES OR OTHER
LIABILITY, WHETHER IN AN ACTION OF CONTRACT, TORT OR OTHERWISE, ARISING FROM,
OUT OF OR IN CONNECTION WITH THE SOFTWARE OR THE USE OR OTHER DEALINGS IN THE
SOFTWARE.*/

#ifndef MAIN_
#define MAIN_

#include"../Control-Module/controller_tasks.hpp"
#include"../PTAM/temp_access_mem.hpp"

//Through spi interface, ECU recieves instructions from main computer

void testPTAM();

#define ENGINE_STATE 0

void setup(){
    Serial.begin(9600);
    CONTROLLER_TASKS *CTobj = new CONTROLLER_TASKS();
    //CTobj -> pin_setup();
    CTobj -> GSE_comms_setup();
    CTobj -> _init_();
    delete CTobj;
}

void loop(){
    CONTROLLER_TASKS *CTobj = new CONTROLLER_TASKS();
    while(1){
        #if ENGINE_STATE == 0 // IDLE
        CTobj -> _IDLE_();
        if(CTobj -> SWITCH2PREP() == 1){
            #undef ENGINE_STATE
            #define ENGINE_STATE 1
        }
        #endif

        #if ENGINE_STATE == 1 // PREP
        CTobj -> _PREP_();
        if(CTobj -> SWITCH2ARMED() == 1){
            #undef ENGINE_STATE
            #define ENGINE_STATE 2
        }
        #endif

        #if ENGINE_STATE == 2 // ARMED
        CTobj -> _ARMED_();
        if(CTobj -> SWITCH2IDLE() == 1){
            #undef ENGINE_STATE
            #define ENGINE_STATE 0
        }
        #endif
        
        #if ENGINE_STATE == 3 // BYPASS
        CTobj -> _bypass_();
        #endif

    }
    delete CTobj;
    testPTAM();
}

void testPTAM(){
    PTAM *obj = new PTAM();
    uint8_t size = obj -> PTAM_ADD_BASE_DOUBLE("345",65);
    Serial.println("tEST");

}

#endif // MAIN_

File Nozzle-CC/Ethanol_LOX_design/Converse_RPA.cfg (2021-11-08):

version = 1.3;
name = "Converse";
info = "";
generalOptions : 
{
  multiphase = true;
  ions = true;
  flowSeparation = true;
};
combustionChamberConditions : 
{
  pressure : 
  {
    value = 50.0;
    unit = "atm";
  };
};
nozzleFlow : 
{
  calculateNozzleFlow = true;
  nozzleInletConditions : 
  {
    contractionAreaRatio = 4.0;
  };
  nozzleExitConditions : 
  {
    pressure : 
    {
      value = 1.0;
      unit = "atm";
    };
  };
  nozzleStations = ( );
};
propellant : 
{
  components : 
  {
    ratio : 
    {
      value = 1.3;
      unit = "O/F";
    };
    oxidizer = ( 
      {
        name = "O2(L)";
        massFraction = 1.0;
        p : 
        {
          value = 0.0;
          unit = "MPa";
        };
      } );
    fuel = ( 
      {
        name = "C2H5OH(L)";
        massFraction = 1.0;
        p : 
        {
          value = 0.0;
          unit = "atm";
        };
      } );
  };
};
engineSize : 
{
  thrust : 
  {
    value = 10.0;
    unit = "kN";
  };
  ambientConditions : 
  {
    value = 0.0;
    unit = "atm";
  };
  chambersNo = 1;
  chamberGeometry : 
  {
    length : 
    {
      value = 1.0;
      unit = "m";
    };
    characteristicLength = true;
    contractionAngle = 30.0;
    R1_to_Rt_ratio = 1.5;
    Rn_to_Rt_ratio = 0.382;
    R2_to_R2max_ratio = 0.5;
  };
};
chamberCooling : 
{
  heatTransfer : 
  {
    relationsType = "Ievlev";
    applyBLC = false;
    numberOfStations = 50;
    radiationHeatTransfer : 
    {
      hotSideWallSurfaceEmissivity = 0.8;
    };
    wallLayerHeight = 0.025;
  };
  chamberCoolingSections = ( 
    {
      radiationCooling : 
      {
        location : 
        {
          value = 0.0;
          unit = "mm";
        };
        length : 
        {
          value = 0.0;
          unit = "m";
        };
        wallThickness : 
        {
          value = 0.0;
          unit = "mm";
        };
        wallConductivity : 
        {
          value = 0.0;
          unit = "W/(m K)";
        };
        coldSideWallSurfaceEmissivity = 0.8;
      };
    } );
  filmSlots = ( );
};
propelantFeedSystem : 
{
  estimateDryMass = false;
};

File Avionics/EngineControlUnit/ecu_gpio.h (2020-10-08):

#ifndef ECU_GPIO_
#define ECU_GPIO_

#include "libs/stm32/spl/variants/stm32f4/src/stm32f4xx_gpio.c"
#include "libs/stm32/cmsis/variants/stm32f4/stm32f4xx.h"

//0x1
#define CLOCK_A (RCC_AHB1Periph_GPIOA)
//0x2
#define CLOCK_B (RCC_AHB1Periph_GPIOB)
//0x4
#define CLOCK_C (RCC_AHB1Periph_GPIOC)
//0x8
#define CLOCK_D (RCC_AHB1Periph_GPIOD)

#define IN 0

#define OUT 1

//Setup Function

void (SETUP_GPIO)(uint8_t PIN,uint32_t _clock_);



void (SET_ECU_GPIO_HIGH)(uint8_t PIN,uint32_t _clock_);

void (SET_ECU_GPIO_LOW)(uint8_t PIN);

void (SET_GPIO_MODE)(uint8_t PIN,uint8_t mode,uint32_t _clock_);



#endif //ECU_GPIO

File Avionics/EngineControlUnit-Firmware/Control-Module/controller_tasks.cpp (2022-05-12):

/*MIT License

Copyright (c) 2020 Nyameaama Gambrah

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
THE SOFTWARE IS PROVIDED "AS IS", WITHOUT WARRANTY OF ANY KIND, EXPRESS OR
IMPLIED, INCLUDING BUT NOT LIMITED TO THE WARRANTIES OF MERCHANTABILITY,
FITNESS FOR A PARTICULAR PURPOSE AND NONINFRINGEMENT. IN NO EVENT SHALL THE
AUTHORS OR COPYRIGHT HOLDERS BE LIABLE FOR ANY CLAIM, DAMAGES OR OTHER
LIABILITY, WHETHER IN AN ACTION OF CONTRACT, TORT OR OTHERWISE, ARISING FROM,
OUT OF OR IN CONNECTION WITH THE SOFTWARE OR THE USE OR OTHER DEALINGS IN THE
SOFTWARE.*/

#include"controller_tasks.hpp"

//Variable noting whether engine has already been prepped
uint8_t prep;
//Variable noting whether engine has been started
uint8_t engineStarted;

//Engine Burn time
double engine_burn_duration_secs;

//Setup pins based on config
void CONTROLLER_TASKS::pin_setup(){
    //Setup MASTER connection for forward neighbor
    //Set SlaveSelection pin as output.
    //uint8_t SlaveSelection = 0; //TEMP
    //pinMode(SlaveSelection, OUTPUT);
    //and Make it HIGH to prevent to start communication right away
    //digitalWrite(SlaveSelection, HIGH);

    //Setup SLAVE connection for backwards neighbor
}

//Setup comms to GSE over NodeMCU SP8266 Wifi
void CONTROLLER_TASKS::GSE_comms_setup(){


}
//Start comms and attach RF interrupt 
//ATTACH PIN NUMBERS
void CONTROLLER_TASKS::_init_(){
    //Start Serial Communication
    //Serial.begin(9600);
    //Setup pins - SPI,sensors, valves
    //SPI
    //pin_setup();
    //SPI.begin();
    //SENSORS

    //VALVES

    REQUESTS *reqObj = new REQUESTS();
    interrupts();
    //attachInterrupt(digitalPinToInterrupt(0),reqObj -> dPassthroughInterrupt,HIGH);
    //attachInterrupt(digitalPinToInterrupt(0),reqObj -> controllerReceiveInterrupt,HIGH);
    delete reqObj;

}

void CONTROLLER_TASKS::_IDLE_(){
    //Controller does nothing
}

//Telemetry checks, peripheral checks
//Engine preconditioning
//Purge, Chill
void CONTROLLER_TASKS::_PREP_(){
    ENGINE_TASKS *obj = new ENGINE_TASKS();
    if(prep != 1){
        //PURGE
        obj -> enginePurge();
        //Delay 30 seconds for possible ground interrupt

        //ENGINE CHILL
        obj -> engineChill();
        //CHECKS



        prep = 1;
    }else{
        //Do nothing.
        //Engine already prepped
    }
    delete obj;
}

void CONTROLLER_TASKS::_ARMED_(){
    ENGINE_TASKS *obj = new ENGINE_TASKS();
    //Engine function wrapped in timer
    if(engineStarted == 1){
        //Get seconds since controller start as current time
        //Log start time
        double start_time = millis();
        if((millis() - start_time) >=  engine_burn_duration_secs){
            obj -> engineShutdown();
            //Reset engine started tag
            engineStarted = 0;
        }
    }else{
        //Start engine
        obj -> engineStartup();
        //Set engine started tag
        engineStarted = 1;
    }
    delete obj;
}

//For manual testing, implement bypass to respond to sensor and valve
//comms without additional processes.
//+1 Overload

//Bypass
//No function overloading possible so search SBC table to 
//determine if return or non-return peripheral !! needs attention !!
void CONTROLLER_TASKS::_bypass_(char* sbc_id){
    REQUESTS *ReqObj = new REQUESTS();
    if(sbc_id){
        //Valve bypass
        //Open valve
        ReqObj -> controllerRequest(sbc_id,1);
        //Close valve
        ReqObj -> controllerRequest(sbc_id,0);
    }else{
        //Sensor bypass
        //Request sensor data
        double data = ReqObj -> controllerRequest(sbc_id,2);
        //transmit_telemetry(data);
    }
}
 //Sensor bypass

//CHange state to idle
uint8_t CONTROLLER_TASKS::SWITCH2IDLE(){
    //Change variable
    uint8_t change = 0;
    //if(compareX(recieve_telemetry(),"IDLE")){
    //    change = 1;
    //}
    return change;
}

//CHange state to prep
uint8_t CONTROLLER_TASKS::SWITCH2PREP(){
    //Change variable
    uint8_t change = 0;
    //if(compareX(recieve_telemetry(),"PREP")){
       // change = 1;
    //}
    return change;
}

//CHange state to armed
uint8_t CONTROLLER_TASKS::SWITCH2ARMED(){
    //Change variable
    uint8_t change = 0;
    //if(compareX(recieve_telemetry(),"ARMED")){
      //  change = 1;
    //}
    return change;
}

//CHange state to bypass
uint8_t CONTROLLER_TASKS::SWITCH2BYPASS(){
    //Change variable
    uint8_t change = 0;
    //if(compareX(recieve_telemetry(),"BYPASS")){
      //  change = 1;
    //}
    return change;
}


//Reset all tags so engine can be preconditioned for another fire
void CONTROLLER_TASKS::reset_(){
    //Reset prep tag
    prep = 0;

    //Reset engine started tag
    engineStarted = 0;
}

//If output = 1, strings match
uint8_t CONTROLLER_TASKS::compareX(char* x, char* y){
    if (x != y){
        return 0;
    }
    else{
        return 1;
    }
}

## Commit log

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2020-09-28 added ECU Abstract Program Chart and Engine docs
    [Converse Engine (Nozzle) v1.xlsx]
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2020-10-04 updated source files and added propellant properties.xlsx
    [Converse ECU controller requirements.xlsx, Converse Engine v1.xlsx, Propellant Properties.xlsx]
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2020-10-09 added ECU casing CAD/drawing and updated source files
    [Converse Engine Component Specifications Log.xlsx, ECU_Casing-V1 v2.f3d]
2020-10-10 refactor to ECU firmware repo
    [Converse ECU controller requirements.xlsx, Schematic1.sch]
2020-10-11 added license print to firmware source files and changes to utility functions
    [Converse Engine v1.xlsx]
2020-10-13 added v1 nozzle CAD and updated nozzle design equations doc
    [Converse Engine v1.xlsx, v1.f3d]
2020-10-15 update to documentation and minimal file-folder repo change
    [Converse Engine v1.xlsx, v1.f3d]
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2020-10-21 Nozzle and CC calculations with additional ECU PCB requirements documented.
    [Converse ECU controller requirements.xlsx]
2020-10-25 added RadioHead library dependency for terminal controller.
    [project.cfg]
2020-10-27 added schematic and cad docs for terminal controller with changes to terminal source files
    [Arduino_uno.6df525b0-a0fc-4683-8e1a-4d70c617ad71.f3d, Component-Dimensions.xlsx]
2020-10-28 changes and additions to equation docs
    [Converse Engine (Nozzle) v1.xlsx, Converse Engine v1.xlsx, Liquid Fuel Rocket Engine Equations.xlsx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]
2020-10-30 minor doc additions to piping and components log
    [Converse Engine Component Specifications Log.xlsx, Piping (prop).xlsx]
2020-11-05 Detailing of electrical pipe breaks and initial PB technical drawing
    [Pipe Break v1 v1.f3d, Pipe Breaks doc.xlsx]
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2020-11-13 spreadsheet changes (nozzle-cc calcs)
    [Converse Engine v1.xlsx, Liquid Fuel Rocket Engine Equations.xlsx]
2020-11-17 added propellant properties docs and additions to spreadsheets + scaled circuit
    [Propellant Properties.xlsx]
2020-11-18 interfacing user flash space on stm32f4 and additions to control
    [Converse Engine v1.xlsx]
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2020-12-03 Pressure loss calculations for propellant lines + update to pipe couplings docs
    [Pipe Break v1 v1.f3d, Pipe Breaks doc.xlsx, Piping (prop) requirements.xlsx]
2020-12-06 bug fixes to terminal controller firmware + PF variant scaled circuit doc changes
    [terminal.ino]
2020-12-08 added cad files for M4, M6, M8 and M10 hex nuts
    [M10 x 1.25 Hex Nut.f3d, M4 x 15mm Screw .f3d, M6 Button Head x 15mm .f3d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]
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2020-12-27 refactor of avionics docs with additions to firmware. Additions to nozzle/cc sheets
    [Converse ECU controller requirements.xlsx, Converse Engine v1.xlsx, ECU_Casing-V1 v2.f3d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]
2021-01-04 additions to peripheral sub controller documentation
    [Peripheral Sub Controllers.xlsx]
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2021-01-14 work on controller power assemblies(Li-ion docs additions + assembly casing additions)
    [Converse Engine v1.xlsx, Li-ion specs.xlsx]
2021-01-16 debugging ecu firmware and work on testing program
    [engine tasks.xlsx]
2021-01-18 added ethanol tap off descriptions and work on documenting ignition sequence
    [engine tasks.xlsx]
2021-01-19 documentation additions with incremental firmware changes
    [Peripheral Sub Controllers.xlsx, engine tasks.xlsx]
2021-01-24 firmware fixes and improvements
    [Peripheral Sub Controllers.xlsx]
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2021-01-28 work on PID feedback control for engine chill task (ecu firmware)
    [Propellant Properties.xlsx]
2021-01-31 work on injector assembly
    [Injector assembly v3.f3d, injector assembly.xlsx]
2021-02-05 Update to AETS to include predefined comparison-based termination circumstances (unfinished)
    [Converse Engine v1.xlsx]
2021-02-13 look over system telemetry/raw data and design equations
    [Converse Engine v1.xlsx]
2021-02-14 ecu firmware changes and additional design docs
    [Converse Engine v1.xlsx]
2021-02-19 written unit-tests for some ecu firmware modules and adiitions to design docs
    [Converse Engine v1.xlsx, Liquid Fuel Rocket Engine Equations.xlsx]
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2021-03-04 minor changes - unit tests (control) + engine mount design specs
    [Engine Mount.xlsx]
2021-03-08 tiny changes everywhere - a shrinking problem
    [Engine Mount.xlsx]
2021-03-10 changes to ecu firmware - mostly
    [Converse Engine v1.xlsx]
2021-03-19 controller firmware changes + doc changes (TODO -> Merge plate design)
    [engine tasks.xlsx]
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2021-04-02 firmware and design changes
    [Converse Engine v1.xlsx]
2021-04-05 tiny changes everywhere - can it get any tinier?
    [Converse Engine v1.xlsx]
2021-04-09 fixed incorrect design stuff, and problems with units, imperial to SI units
    [Converse Engine v1.xlsx]
2021-04-18 unit tests for PTAM + injector stuff
    [Converse Engine v1.xlsx]
2021-04-23 tiny changes everywhere - has anything even changed?
    [Converse Engine v1.xlsx, injector assembly.xlsx]
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2021-05-31 moved some stuff. updated SBC comms docs with new ring topology network config
    [Converse ECU controller requirements.xlsx, Schematic1.sch]
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2021-07-21 new documentation for sbc power config and other changes
    [Converse Engine v1.xlsx, Converse-B.xlsx]
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2021-08-21 is this big enough to call a commit?
    [Converse Engine v1.xlsx]
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2022-02-09 injector body CAD changes and propellant pipes CAD additions
    [Converse_Assembly.CATProduct, Converse_ThrustChamber.CATPart, Ebay2.CATProduct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]
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
